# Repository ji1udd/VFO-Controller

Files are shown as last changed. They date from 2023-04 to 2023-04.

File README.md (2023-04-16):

# VFO-Controller
MIDI Controller over USB for Thetis, PowerSDR.  
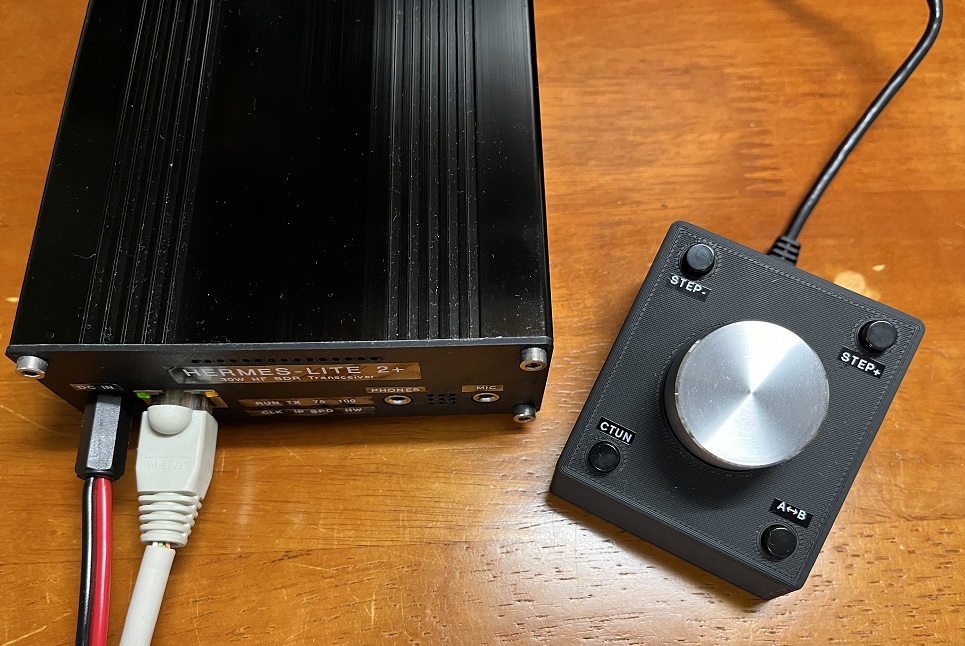
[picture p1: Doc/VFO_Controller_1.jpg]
  
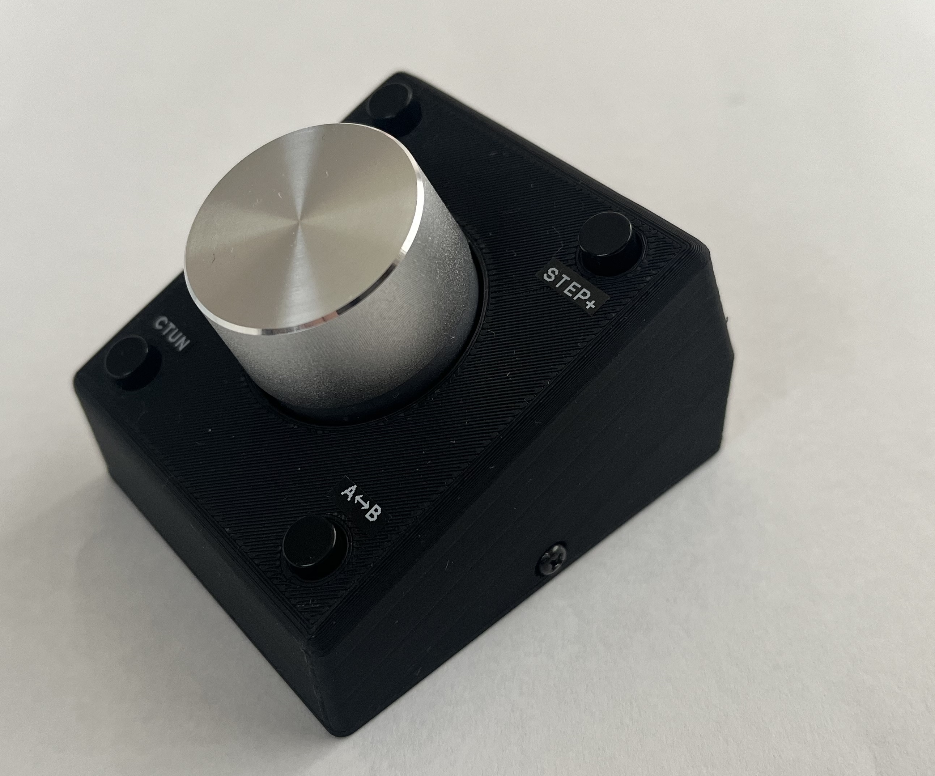
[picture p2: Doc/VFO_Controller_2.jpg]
  
## Hardware
It consists of an Arduino Pro Micro (AliExpress), a rotary encoder and four push switches, and can be made with a very simple circuit at a low cost. There are still unused terminals on the Arduino, but I made it a controller that only has functions related to VFO.  
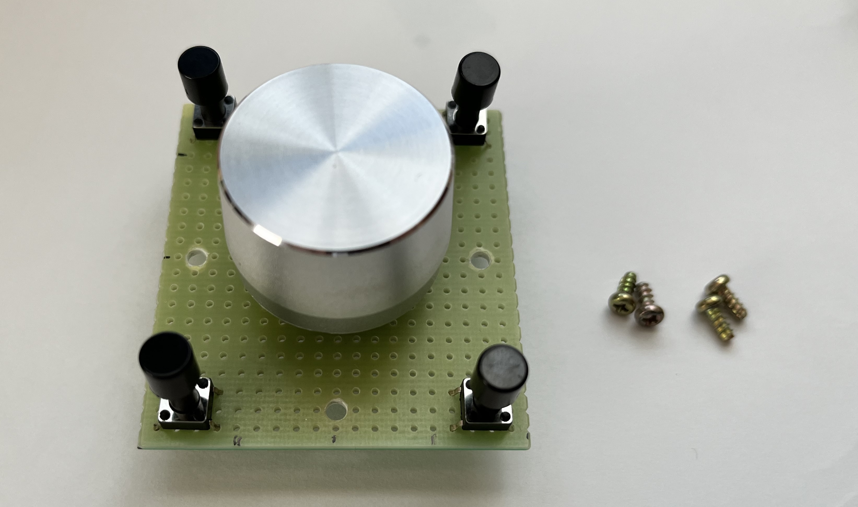
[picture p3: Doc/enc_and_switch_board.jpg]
  
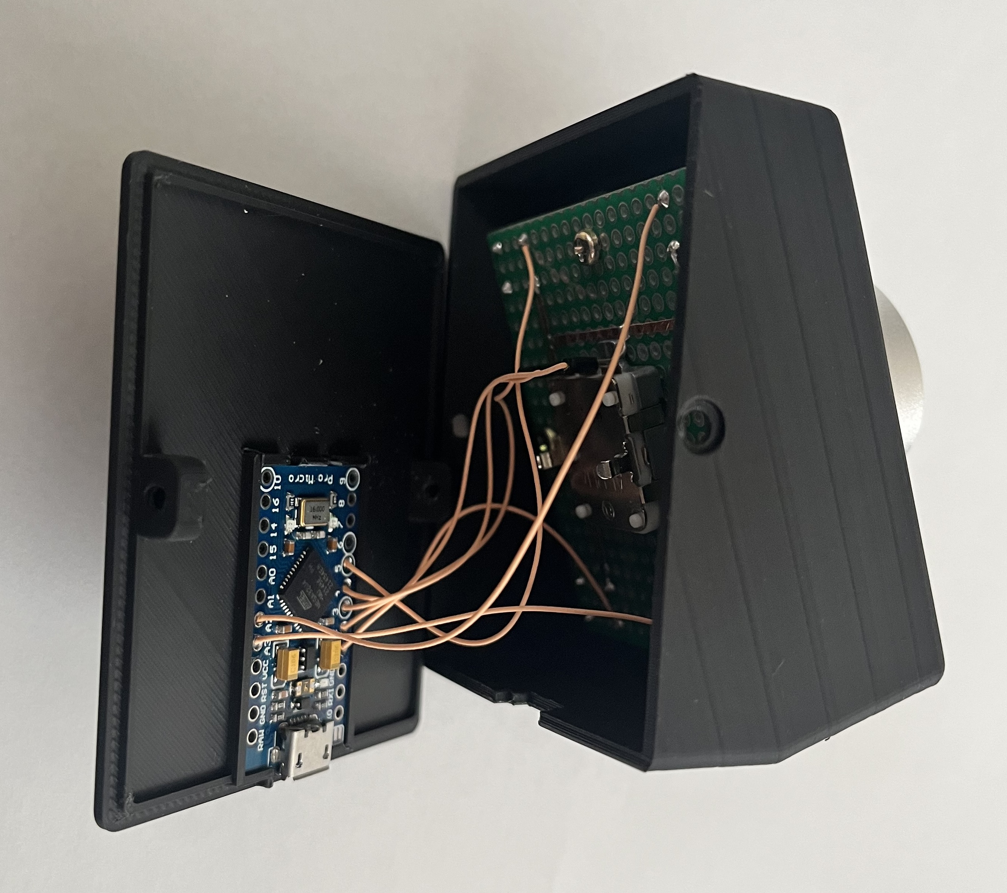
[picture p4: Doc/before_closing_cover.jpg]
  
## Parts
- Arduino Pro Micro : 5V / 16MHz (AliExpress)
- Rotary Encoder :  KY040 encoder can be used (AliExpress). In my case, RE160F-40E3-20A-24P in my stock is used.
- Tactile Switch and Cap : (AliExpress)  
Refer to the photos and datasheet in Doc folder for these dimensions.  
## Software
It's also simple. Almost no programming is needed with using nice midi [_Control-Surface library_](https://github.com/tttapa/Control-Surface).  
## Enclosure
It's made with 3D printer. I used a knob removed from a junk audio set.  
## Thetis/PowerSDR setting
Encoder and switches are configurable freely.  Here is my setting.
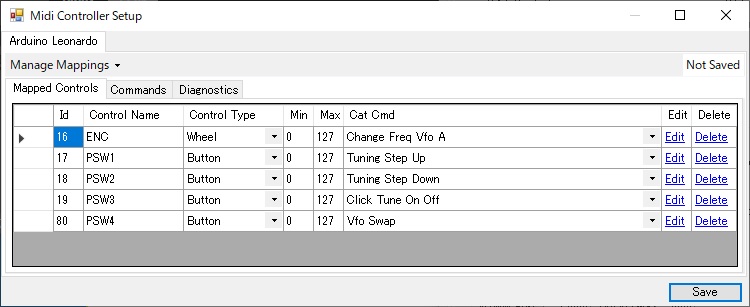
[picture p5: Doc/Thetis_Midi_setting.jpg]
  
I found [_useful youtube video_](https://www.youtube.com/watch?v=X81hrYqUJiQ&t=628s) to configure.

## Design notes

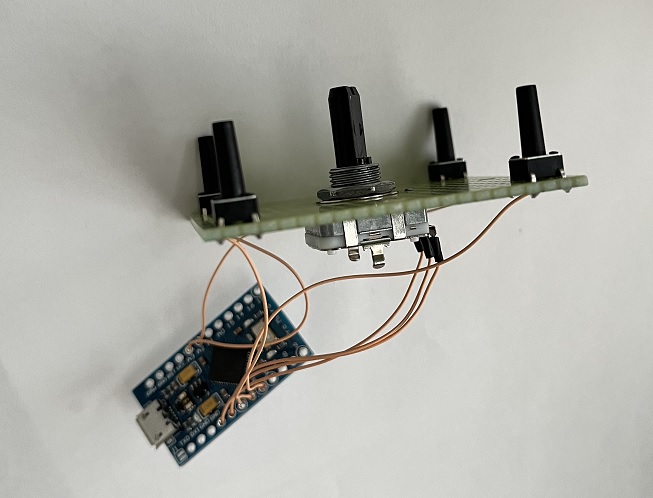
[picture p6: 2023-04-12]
Doc/board_enc_and_switches.jpg

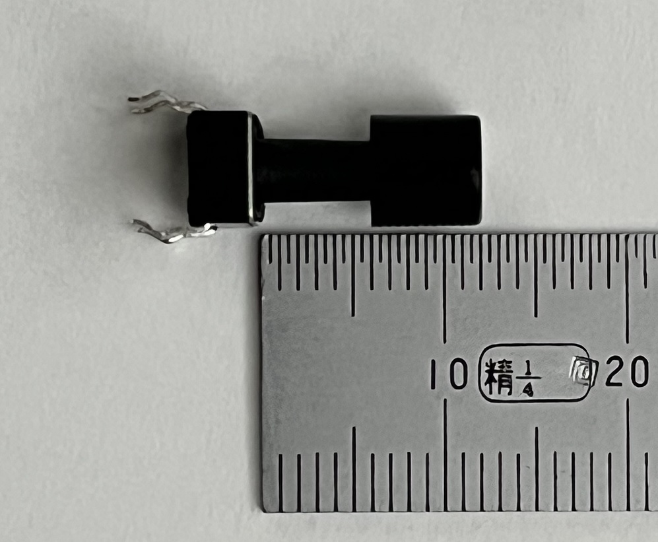
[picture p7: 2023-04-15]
Doc/SWTotalHeight.jpg

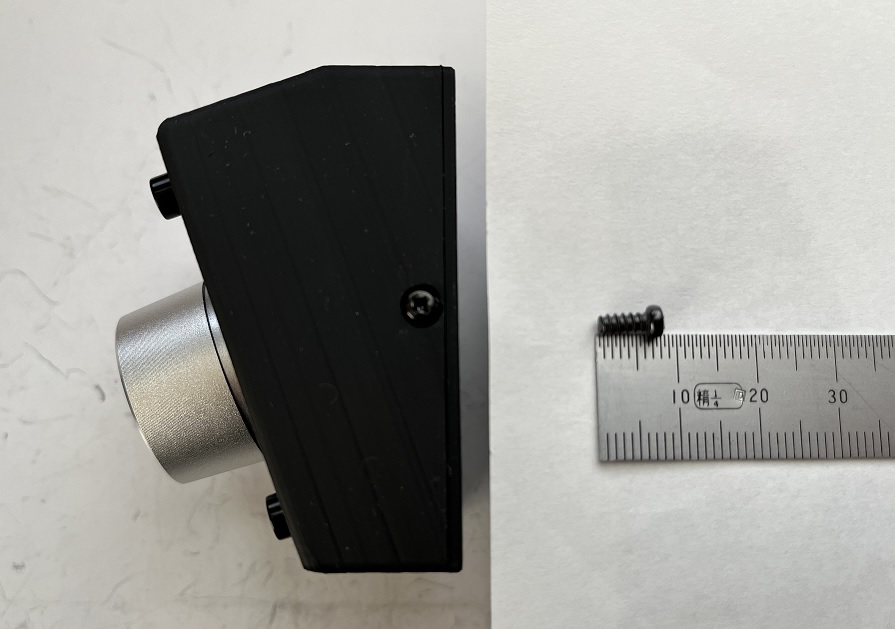
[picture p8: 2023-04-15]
Doc/side_view_and_screw.jpg

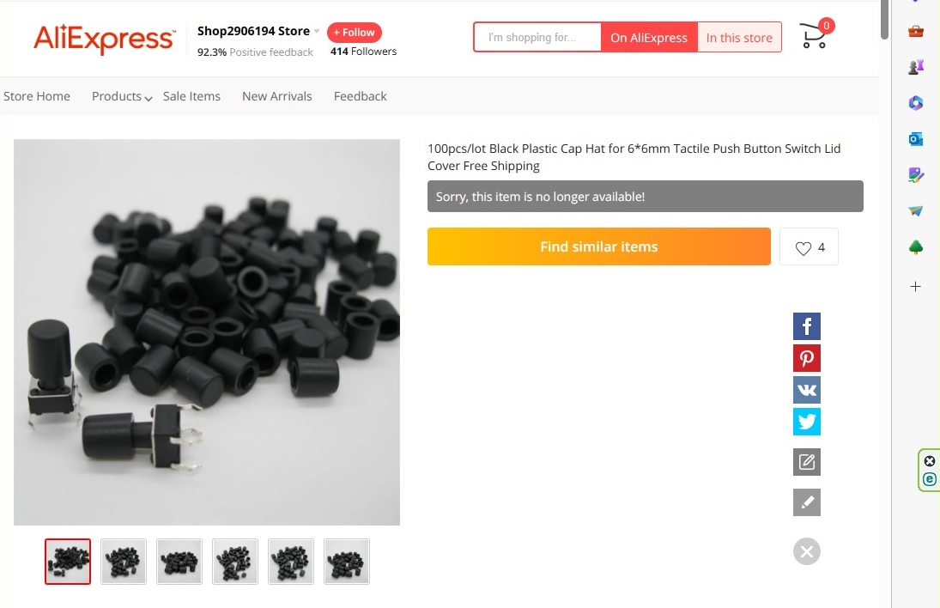
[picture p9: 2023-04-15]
Doc/Shop2906194(Not Available Now)_SwitchLid_info1.jpg

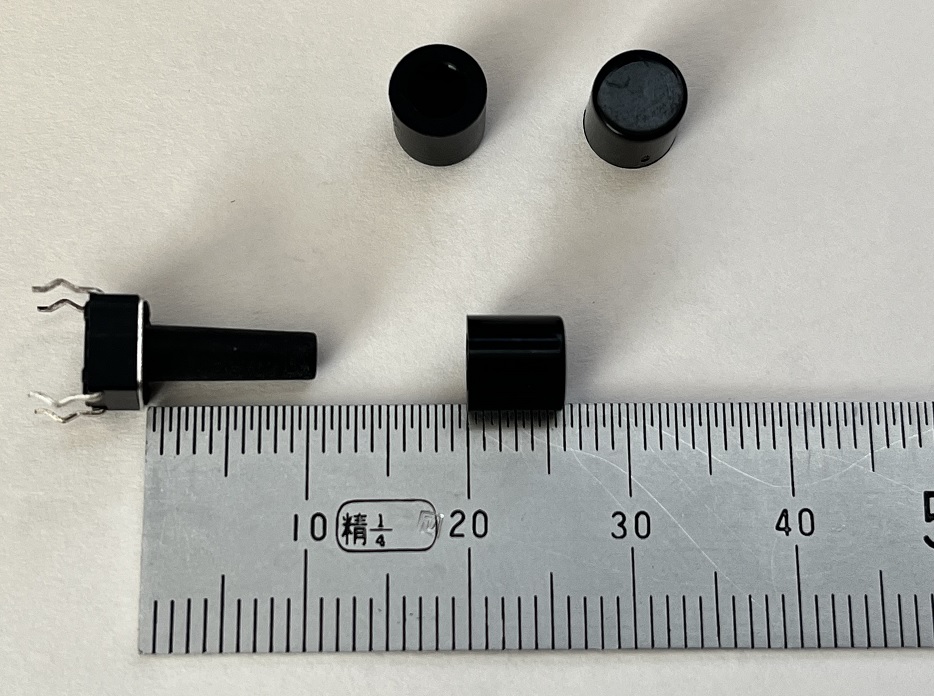
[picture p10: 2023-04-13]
Doc/TactileSW_and_Cap_AliExpress.jpg

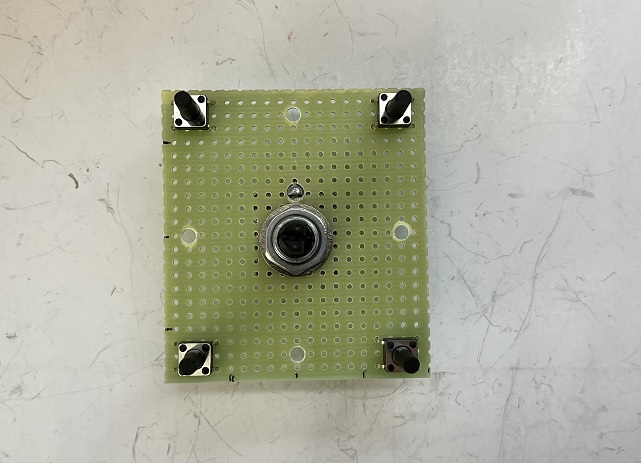
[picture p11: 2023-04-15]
Doc/mount_enc_sw.jpg

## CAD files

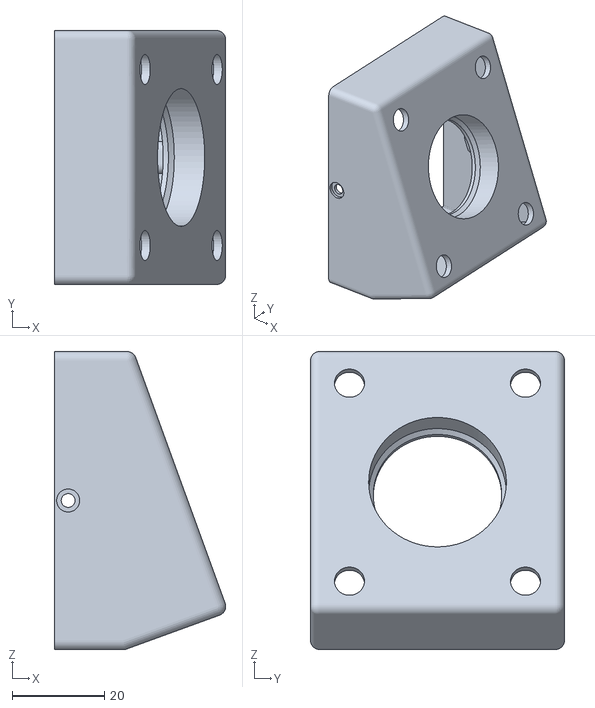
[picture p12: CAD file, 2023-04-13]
3D_Print/VFO_Controller_body_v1.stl
37.1 x 55.0 x 64.5

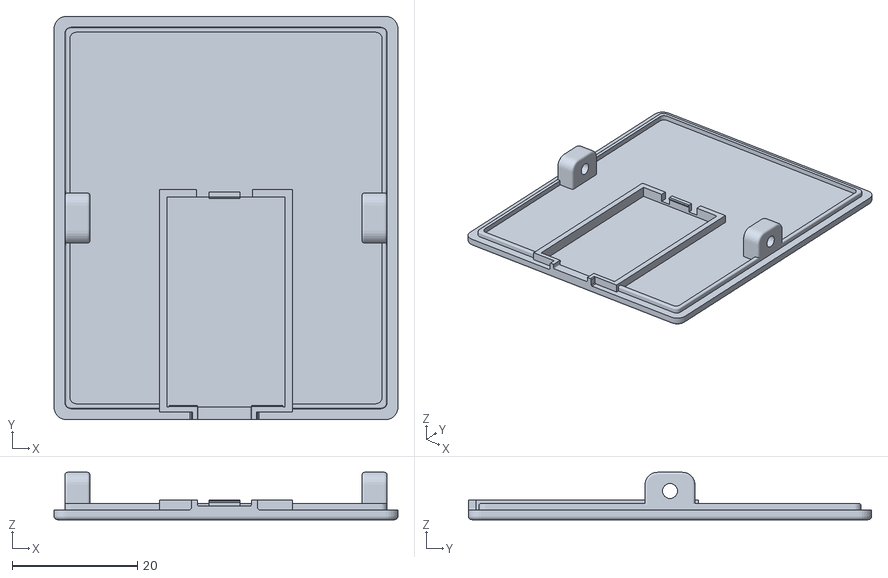
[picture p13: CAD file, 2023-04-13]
3D_Print/VFO_Controller_cover_v2.stl
55.0 x 64.5 x 7.60

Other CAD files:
3D_Print/Knob_v1_model_for_checking_enclosure_design.f3d

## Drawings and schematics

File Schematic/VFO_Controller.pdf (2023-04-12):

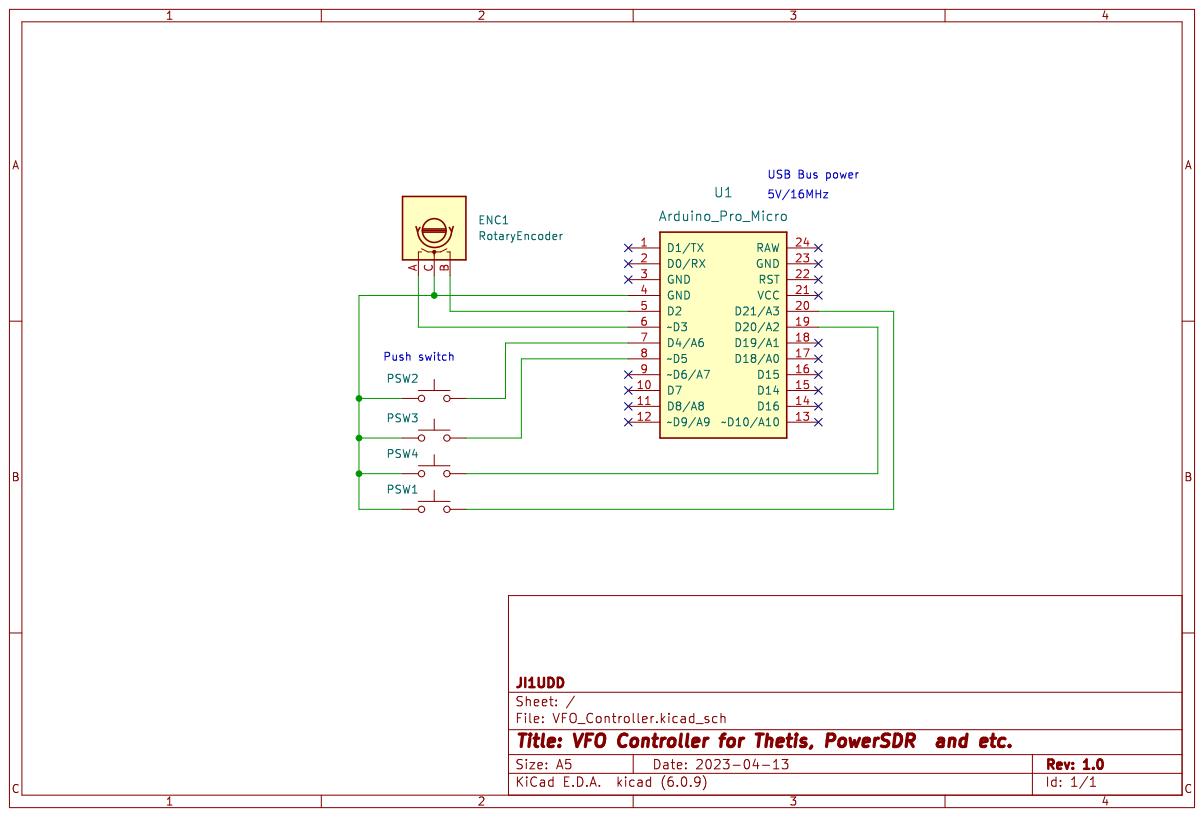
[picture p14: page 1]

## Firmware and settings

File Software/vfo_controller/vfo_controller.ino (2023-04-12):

#include <Control_Surface.h> // Control Surface library by Pieter P (tttapa)

// PIN for Aruduino Pro Micro
#define PIN_ENC_A   (3) // GPIO3
#define PIN_ENC_B   (2) // GPIO2
#define PIN_PSW1   (A3) // A3
#define PIN_PSW2    (4) // GPIO4
#define PIN_PSW3    (5) // GPIO5
#define PIN_PSW4   (A2) // A2

// Instantiate a MIDI over USB interface.
USBMIDI_Interface midi;

// Instantiate a CCRotaryEncoder object
CCRotaryEncoder enc {
  {PIN_ENC_A, PIN_ENC_B},           // pins
  MCU::V_POT_1,                     // MIDI address (CC number + optional channel)
  1,                                // optional multiplier if the control isn't fast enough
};

// Instantiate a CCButton object
CCButton pushswitches[] {
  { PIN_PSW1, {MIDI_CC::General_Purpose_Controller_2, CHANNEL_1} },  // upper right button
  { PIN_PSW2, {MIDI_CC::General_Purpose_Controller_3, CHANNEL_1} },  // upper left button
  { PIN_PSW3, {MIDI_CC::General_Purpose_Controller_4, CHANNEL_1} },  // lower left button
  { PIN_PSW4, {MIDI_CC::General_Purpose_Controller_5, CHANNEL_1} },  // lower right button
};

void setup() {
  RelativeCCSender::setMode(relativeCCmode::TWOS_COMPLEMENT);
  Control_Surface.begin(); // Initialize Control Surface
}

void loop() {
  Control_Surface.loop(); // Update the Control Surface
}

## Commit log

2023-04-13 Added enclosure data
    [Knob_v1_model_for_checking_enclosure_design.f3d, VFO_Controller_body_v1.stl, VFO_Controller_cover_v2.stl]
2023-04-14 added the encoder datasheet for dimensional reference
2023-04-15 Added switch cap photo
